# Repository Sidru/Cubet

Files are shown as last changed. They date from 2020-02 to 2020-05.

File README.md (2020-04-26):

# Cubet (CUBID-19) 

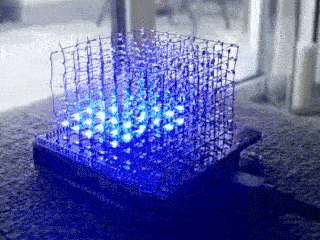
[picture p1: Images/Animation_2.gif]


Cubet, a small single color led cube, build during the Covid-19 Quarantine

:warning: The README is still in working process

:warning: The Software works, but it must be improved. Trying to get the DMA to work with the Timer Counter to automatic set the LATCH output. The animations must be still coded (I've copied some animations and functions from [fuchsales/LED-Cube](https://github.com/fuchsalex/LED-Cube)

I always wanted a LED Cube, a compact one with smd leds. I also wanted to give KiCad a try (I've been Eagle user for a couple of years). That's why I started this mini project.

My goal was: 
- Small LED Cube, not bigger than 5cm
- No extra power needed (USB powered)
- Cheap (i.e. Shift Register instead of "expensive" LED Drivers, no SK6812/ws2811 leds)
- Designed with KiCad

I started with the Schematic and Layout in January, and the PCB came together with COVID, so I had plenty of time to solder.
I gave my cube the name of Cubet (catalan word for small cube), but CUBID is also a good name :)

The microcontroller is a SAMD21, with native USB, so no FTDI or similar is needed. It' a simple Arduino Zero compatible board, like the Feather M0 from Adafruit
It uses 74HC595 Shift Registers and a couple of transistors.

My tools are not the best one, and I realized I may need to buy better and new tools. For example my soldering iron is a cheap one and the soldering was quite a challenge (The head was too big for some components, and it didn't get hot enough). 
I also may need a Microscope, it's more pleasant than a magnifying glass. The tweezers were of course also too big. 

For the LED Matrix/Cube I need to develope a helping tool or something similar. My idea was to use 8 big holes in the PCB to put there 8 LEDS and solder them together to get a column. This didn't work as expected so I neede to solder without help.
I used 0.3mm Wire for the columns, and 0.2mm Wire for the rest.

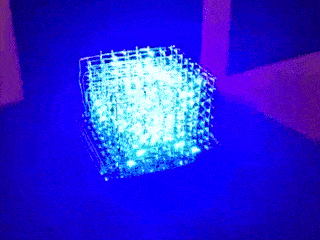
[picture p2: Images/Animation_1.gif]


## Getting Started

* Install KiCad and make changes to the schematic/layout (if needed)
* Get the PCB from your favourite Producer
* Solder all the components
* Flash the Bootloader (if needed)
* Flash the Software

#### Prerequisites

* A lot of time 
* Patience
* More patience
* Soldering skill
* JTAG Programmer (I used an J\-LINK EDU Mini)
* More time
* Did I mention patience?

### Installing 
#### Flashing the Bootloader
#### Flashing the Software

## Built With

* [KiCad](http://www.kicad-pcb.org)
* [PlatformIO](http://platformio.org)

## Authors

## License

This project is licensed under the Apache License - see the [LICENSE.md](LICENSE.md) file for tedtails

## Acknowledgments

[LED-Cube](https://github.com/fuchsalex/LED-Cube)
[Mini KiCad Tutorial](https://github.com/MalphasWats/hawk)
[KiCad Freerouting](https://github.com/miho/freerouting)
[Gerber Export](https://jnduli.co.ke/prepare-kicad-pcb-elecrow.html)
[PCB from Elecrow](https://www.elecrow.com/pcb-manufacturing.html)
[SAMD21](http://ww1.microchip.com/downloads/en/DeviceDoc/SAM_D21_DA1_Family_DataSheet_DS40001882F.pdf)
[SAMD21 GDB](https://learn.adafruit.com/debugging-the-samd21-with-gdb/setup)
[SAMD21 Bootloader Protection](https://roamingthings.de/posts/use-j-link-to-change-the-boot-loader-protection-of-a-sam-d21)
[Programming a SAMD bootloader using JLink & Linux](https://hackaday.io/page/5997-programming-a-samd-bootloader-using-jlink-linux)
[SAMD21\_DMA](https://aykevl.nl/2019/09/samd21-dma)
[Adafruit\_ZeroDMA](https://github.com/adafruit/Adafruit\_ZeroDMA)

## Future changes

* RGB leds 
* ESP32 for Blueetoth and WLAN
* SPI, I2C and UART connectors for hardware "upgrades"
* Battery connector and battery charging
* Maybe a 12x12x12 and a 16x16x16 version
* SD card for animations without programming

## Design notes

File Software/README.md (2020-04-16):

https://github.com/fuchsalex/LED-Cube/blob/master/Sourcecode/LED_CUBE_source.ino

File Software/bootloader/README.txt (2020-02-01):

https://learn.adafruit.com/debugging-the-samd21-with-gdb/overview
https://hackaday.io/page/5997-programming-a-samd-bootloader-using-jlink-linux
https://roamingthings.de/posts/use-j-link-to-change-the-boot-loader-protection-of-a-sam-d21/

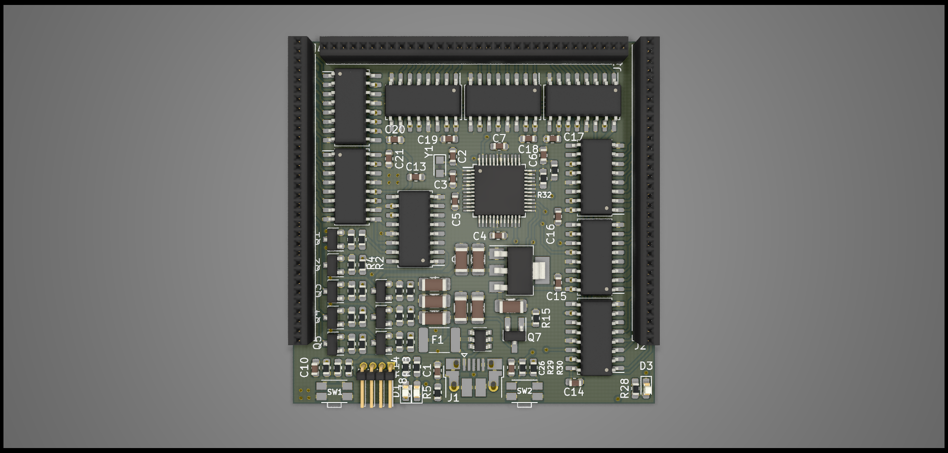
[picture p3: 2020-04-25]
Images/Cubet_PCB.png

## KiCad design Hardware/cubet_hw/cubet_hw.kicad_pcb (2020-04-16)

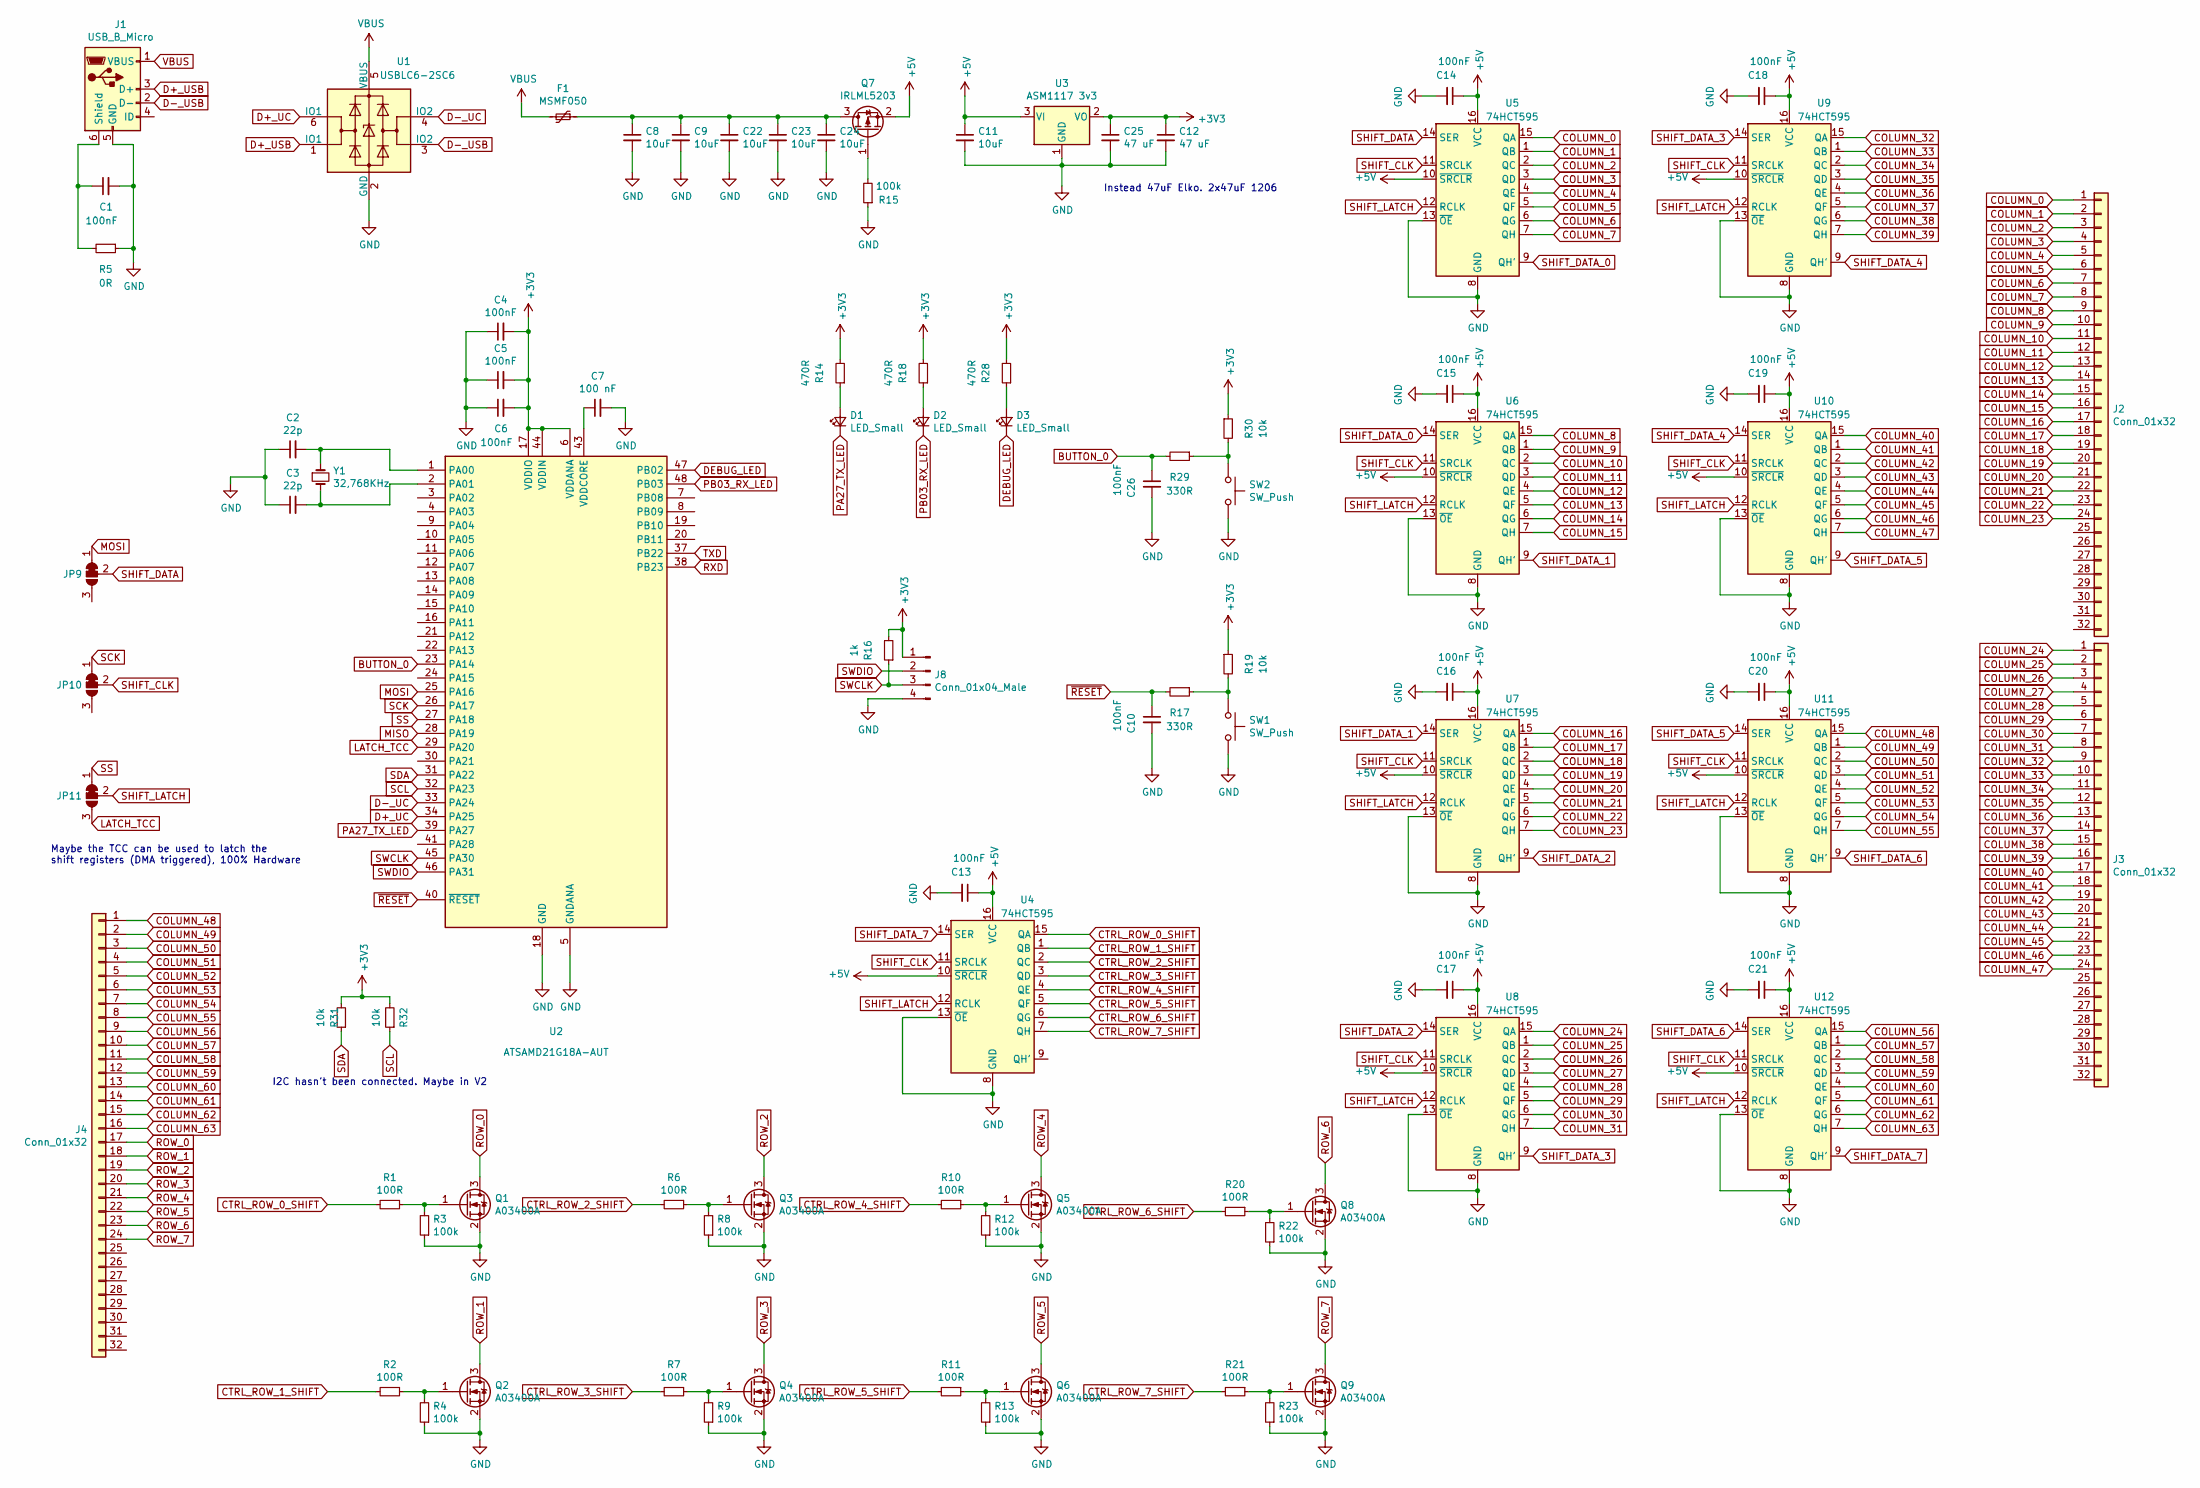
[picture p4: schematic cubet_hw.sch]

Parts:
C1, C4, C5, C6, C10, C13, C14, C15, C16, C17, C18, C19, C20, C21, C26: 100nF; C_0603_1608Metric
C2, C3: 22p; C_0603_1608Metric
C7: 100 nF; C_0603_1608Metric
C8, C9, C11, C22, C23, C24: 10uF; C_1206_3216Metric_Pad1.42x1.75mm_HandSolder
C12, C25: 47 uF; C_1206_3216Metric_Pad1.42x1.75mm_HandSolder
D1, D2, D3: LED_Small; LED_0603_1608Metric_Pad1.05x0.95mm_HandSolder
F1: MSMF050; Fuse_1812_4532Metric_Pad1.30x3.40mm_HandSolder
J1: USB_B_Micro; USB_Micro-B_Amphenol_10103594-0001LF_Horizontal
J2, J3, J4: Conn_01x32; PinSocket_1x32_P1.27mm_Vertical
J8: Conn_01x04_Male; PinHeader_1x04_P1.27mm_Horizontal
JP9, JP10, JP11: SolderJumper_3_Bridged12; SolderJumper-3_P1.3mm_Bridged12_RoundedPad1.0x1.5mm
Q1, Q2, Q3, Q4, Q5, Q6, Q8, Q9: A03400A; SOT-23
Q7: IRLML5203; SOT-23_Handsoldering
R1, R2, R6, R7, R10, R11, R20, R21: 100R; R_0603_1608Metric_Pad1.05x0.95mm_HandSolder
R3, R4, R8, R9, R12, R13, R22, R23: 100k; R_0603_1608Metric_Pad1.05x0.95mm_HandSolder
R5: 0R; R_0603_1608Metric
R14, R18, R28: 470R; R_0603_1608Metric_Pad1.05x0.95mm_HandSolder
R15: 100k; R_0603_1608Metric
R16: 1k; R_0603_1608Metric
R17, R29: 330R; R_0603_1608Metric
R19, R30: 10k; R_0603_1608Metric
R31, R32: 10k; R_0603_1608Metric_Pad1.05x0.95mm_HandSolder
SW1, SW2: SW_Push; SW_SPST_EVQP7A
U1: USBLC6-2SC6; SOT-23-6
U2: ATSAMD21G18A-AUT; TQFP-48_7x7mm_P0.5mm
U3: ASM1117 3v3; SOT-223
U4, U5, U6, U7, U8, U9, U10, U11, U12: 74HCT595; SOP-16_4.55x10.3mm_P1.27mm
Y1: 32,768KHz; Crystal_SMD_2012-2Pin_2.0x1.2mm_HandSoldering

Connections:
+3V3: C4.2, C5.2, C6.2, C12.1, C25.1, J8.1, R14.2, R16.2, R18.2, R19.1, R28.2, R30.1, R31.2, R32.2, U2.6 (VDDANA), U2.17 (VDDIO), U2.36 (VDDIO), U2.44 (VDDIN), U3.2 (VO)
+5V: C11.1, C13.1, C14.1, C15.1, C16.1, C17.1, C18.1, C19.1, C20.1, C21.1, Q7.2 (S), U3.3 (VI), U4.10 (~SRCLR), U4.16 (VCC), U5.10 (~SRCLR), U5.16 (VCC), U6.10 (~SRCLR), U6.16 (VCC), U7.10 (~SRCLR), U7.16 (VCC), U8.10 (~SRCLR), U8.16 (VCC), U9.10 (~SRCLR), U9.16 (VCC), U10.10 (~SRCLR), U10.16 (VCC), U11.10 (~SRCLR), U11.16 (VCC), U12.10 (~SRCLR), U12.16 (VCC)
BUTTON_0: C26.1, R29.2, U2.23 (PA14)
COLUMN_0: J2.1, U5.15 (QA)
COLUMN_1: J2.2, U5.1 (QB)
COLUMN_2: J2.3, U5.2 (QC)
COLUMN_3: J2.4, U5.3 (QD)
COLUMN_4: J2.5, U5.4 (QE)
COLUMN_5: J2.6, U5.5 (QF)
COLUMN_6: J2.7, U5.6 (QG)
COLUMN_7: J2.8, U5.7 (QH)
COLUMN_8: J2.9, U6.15 (QA)
COLUMN_9: J2.10, U6.1 (QB)
COLUMN_10: J2.11, U6.2 (QC)
COLUMN_11: J2.12, U6.3 (QD)
COLUMN_12: J2.13, U6.4 (QE)
COLUMN_13: J2.14, U6.5 (QF)
COLUMN_14: J2.15, U6.6 (QG)
COLUMN_15: J2.16, U6.7 (QH)
COLUMN_16: J2.17, U7.15 (QA)
COLUMN_17: J2.18, U7.1 (QB)
COLUMN_18: J2.19, U7.2 (QC)
COLUMN_19: J2.20, U7.3 (QD)
COLUMN_20: J2.21, U7.4 (QE)
COLUMN_21: J2.22, U7.5 (QF)
COLUMN_22: J2.23, U7.6 (QG)
COLUMN_23: J2.24, U7.7 (QH)
COLUMN_24: J3.1, U8.15 (QA)
COLUMN_25: J3.2, U8.1 (QB)
COLUMN_26: J3.3, U8.2 (QC)
COLUMN_27: J3.4, U8.3 (QD)
COLUMN_28: J3.5, U8.4 (QE)
COLUMN_29: J3.6, U8.5 (QF)
COLUMN_30: J3.7, U8.6 (QG)
COLUMN_31: J3.8, U8.7 (QH)
COLUMN_32: J3.9, U9.15 (QA)
COLUMN_33: J3.10, U9.1 (QB)
COLUMN_34: J3.11, U9.2 (QC)
COLUMN_35: J3.12, U9.3 (QD)
COLUMN_36: J3.13, U9.4 (QE)
COLUMN_37: J3.14, U9.5 (QF)
COLUMN_38: J3.15, U9.6 (QG)
COLUMN_39: J3.16, U9.7 (QH)
COLUMN_40: J3.17, U10.15 (QA)
COLUMN_41: J3.18, U10.1 (QB)
COLUMN_42: J3.19, U10.2 (QC)
COLUMN_43: J3.20, U10.3 (QD)
COLUMN_44: J3.21, U10.4 (QE)
COLUMN_45: J3.22, U10.5 (QF)
COLUMN_46: J3.23, U10.6 (QG)
COLUMN_47: J3.24, U10.7 (QH)
COLUMN_48: J4.1, U11.15 (QA)
COLUMN_49: J4.2, U11.1 (QB)
COLUMN_50: J4.3, U11.2 (QC)
COLUMN_51: J4.4, U11.3 (QD)
COLUMN_52: J4.5, U11.4 (QE)
COLUMN_53: J4.6, U11.5 (QF)
COLUMN_54: J4.7, U11.6 (QG)
COLUMN_55: J4.8, U11.7 (QH)
COLUMN_56: J4.9, U12.15 (QA)
COLUMN_57: J4.10, U12.1 (QB)
COLUMN_58: J4.11, U12.2 (QC)
COLUMN_59: J4.12, U12.3 (QD)
COLUMN_60: J4.13, U12.4 (QE)
COLUMN_61: J4.14, U12.5 (QF)
COLUMN_62: J4.15, U12.6 (QG)
COLUMN_63: J4.16, U12.7 (QH)
CTRL_ROW_0_SHIFT: R1.2, U4.15 (QA)
CTRL_ROW_0_UC: U2.9 (PA04)
CTRL_ROW_1_SHIFT: R2.2, U4.1 (QB)
CTRL_ROW_1_UC: U2.10 (PA05)
CTRL_ROW_2_SHIFT: R6.2, U4.2 (QC)
CTRL_ROW_2_UC: U2.11 (PA06)
CTRL_ROW_3_SHIFT: R7.2, U4.3 (QD)
CTRL_ROW_3_UC: U2.12 (PA07)
CTRL_ROW_4_SHIFT: R10.2, U4.4 (QE)
CTRL_ROW_4_UC: U2.13 (PA08)
CTRL_ROW_5_SHIFT: R11.2, U4.5 (QF)
CTRL_ROW_5_UC: U2.14 (PA09)
CTRL_ROW_6_SHIFT: R20.2, U4.6 (QG)
CTRL_ROW_6_UC: U2.15 (PA10)
CTRL_ROW_7_SHIFT: R21.2, U4.7 (QH)
CTRL_ROW_7_UC: U2.16 (PA11)
D+_UC: U1.6 (IO1), U2.34 (PA25)
D+_USB: J1.3 (D+), U1.1 (IO1)
D-_UC: U1.4 (IO2), U2.33 (PA24)
D-_USB: J1.2 (D-), U1.3 (IO2)
DEBUG_LED: D3.1 (K), U2.47 (PB02)
GND: C1.2, C2.1, C3.1, C4.1, C5.1, C6.1, C7.2, C8.2, C9.2, C10.2, C11.2, C12.2, C13.2, C14.2, C15.2, C16.2, C17.2, C18.2, C19.2, C20.2, C21.2, C22.2, C23.2, C24.2, C25.2, C26.2, J1.5 (GND), J8.4, Q1.2 (S), Q2.2 (S), Q3.2 (S), Q4.2 (S), Q5.2 (S), Q6.2 (S), Q8.2 (S), Q9.2 (S), R3.1, R4.1, R5.1, R8.1, R9.1, R12.1, R13.1, R15.1, R22.1, R23.1, SW1.2, SW2.2, U1.2 (GND), U2.5 (GNDANA), U2.18 (GND), U2.35 (GND), U2.42 (GND), U3.1 (GND), U4.8 (GND), U4.13 (~OE), U5.8 (GND), U5.13 (~OE), U6.8 (GND), U6.13 (~OE), U7.8 (GND), U7.13 (~OE), U8.8 (GND), U8.13 (~OE), U9.8 (GND), U9.13 (~OE), U10.8 (GND), U10.13 (~OE), U11.8 (GND), U11.13 (~OE), U12.8 (GND), U12.13 (~OE)
LATCH_TCC: JP11.3 (B), U2.29 (PA20)
MISO: U2.28 (PA19)
MOSI: JP9.1 (A), U2.25 (PA16)
unnamed: C1.1, J1.6 (Shield), R5.2
unnamed: C2.2, U2.1 (PA00), Y1.1
unnamed: C3.2, U2.2 (PA01), Y1.2
unnamed: C7.1, U2.43 (VDDCORE)
unnamed: C8.1, C9.1, C22.1, C23.1, C24.1, F1.1, Q7.3 (D)
unnamed: D1.2 (A), R14.1
unnamed: D2.2 (A), R18.1
unnamed: D3.2 (A), R28.1
unnamed: Q1.1 (G), R1.1, R3.2
unnamed: Q2.1 (G), R2.1, R4.2
unnamed: Q3.1 (G), R6.1, R8.2
unnamed: Q4.1 (G), R7.1, R9.2
unnamed: Q5.1 (G), R10.1, R12.2
unnamed: Q6.1 (G), R11.1, R13.2
unnamed: Q7.1 (G), R15.2
unnamed: Q8.1 (G), R20.1, R22.2
unnamed: Q9.1 (G), R21.1, R23.2
unnamed: R17.1, R19.2, SW1.1
unnamed: R29.1, R30.2, SW2.1
PA27_TX_LED: D1.1 (K), U2.39 (PA27)
PB03_RX_LED: D2.1 (K), U2.48 (PB03)
PB10_S4_SPI_MOSI: U2.19 (PB10)
PB11_S4_SPI_SCK: U2.20 (PB11)
PB12_S4_SPI_MISO: U2.21 (PA12)
ROW_0: J4.17, Q1.3 (D)
ROW_1: J4.18, Q2.3 (D)
ROW_2: J4.19, Q3.3 (D)
ROW_3: J4.20, Q4.3 (D)
ROW_4: J4.21, Q5.3 (D)
ROW_5: J4.22, Q6.3 (D)
ROW_6: J4.23, Q8.3 (D)
ROW_7: J4.24, Q9.3 (D)
RXD: U2.38 (PB23)
SCK: JP10.1 (A), U2.26 (PA17)
SCL: R32.1, U2.32 (PA23)
SDA: R31.1, U2.31 (PA22)
SHIFT_CLK: JP10.2 (C), U4.11 (SRCLK), U5.11 (SRCLK), U6.11 (SRCLK), U7.11 (SRCLK), U8.11 (SRCLK), U9.11 (SRCLK), U10.11 (SRCLK), U11.11 (SRCLK), U12.11 (SRCLK)
SHIFT_DATA: JP9.2 (C), U5.14 (SER)
SHIFT_DATA_0: U5.9 (QH'), U6.14 (SER)
SHIFT_DATA_1: U6.9 (QH'), U7.14 (SER)
SHIFT_DATA_2: U7.9 (QH'), U8.14 (SER)
SHIFT_DATA_3: U8.9 (QH'), U9.14 (SER)
SHIFT_DATA_4: U9.9 (QH'), U10.14 (SER)
SHIFT_DATA_5: U10.9 (QH'), U11.14 (SER)
SHIFT_DATA_6: U11.9 (QH'), U12.14 (SER)
SHIFT_DATA_7: U4.14 (SER), U12.9 (QH')
SHIFT_LATCH: JP11.2 (C), U4.12 (RCLK), U5.12 (RCLK), U6.12 (RCLK), U7.12 (RCLK), U8.12 (RCLK), U9.12 (RCLK), U10.12 (RCLK), U11.12 (RCLK), U12.12 (RCLK)
SS: JP11.1 (A), U2.27 (PA18)
SWCLK: J8.3, R16.1, U2.45 (PA30)
SWDIO: J8.2, U2.46 (PA31)
TXD: U2.37 (PB22)
VBUS: F1.2, J1.1 (VBUS), U1.5 (VBUS)
~RESET~: C10.1, R17.2, U2.40 (~RESET)

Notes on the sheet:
Instead 47uF Elko. 2x47uF 1206
Maybe the TCC can be used to latch the shift registers (DMA triggered), 100% Hardware
I2C hasn't been connected. Maybe in V2

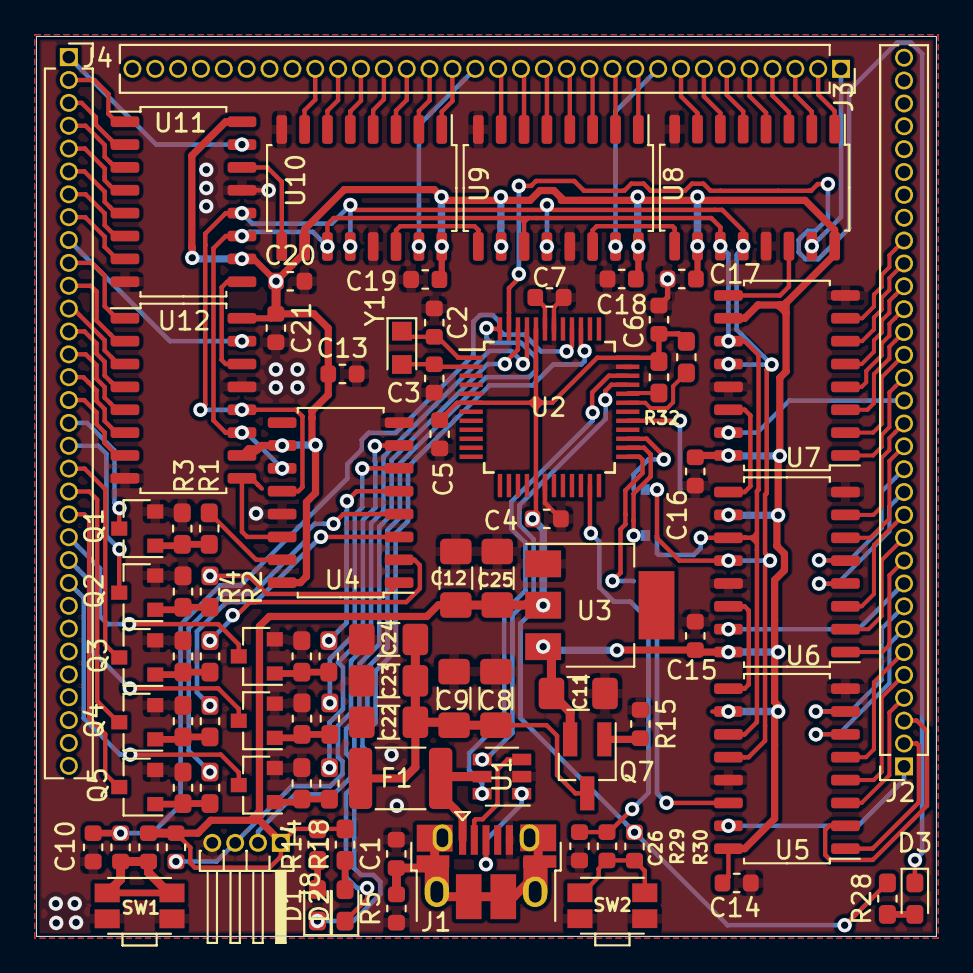
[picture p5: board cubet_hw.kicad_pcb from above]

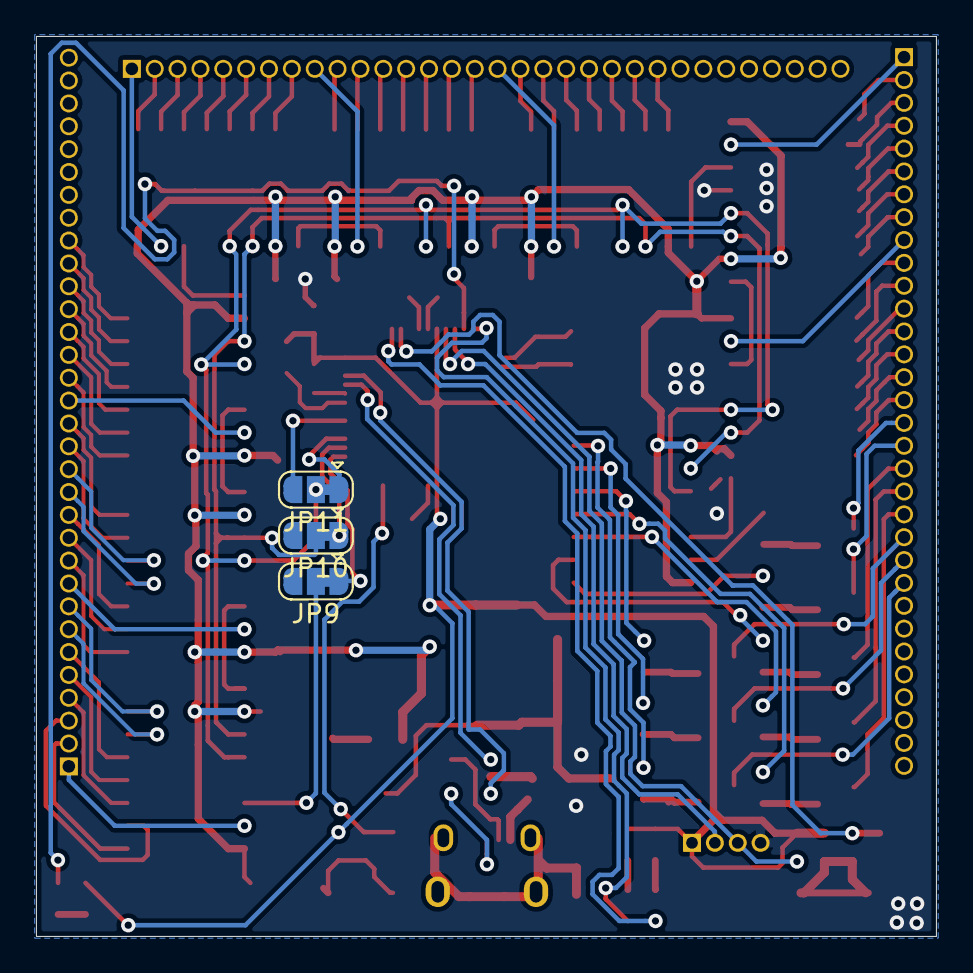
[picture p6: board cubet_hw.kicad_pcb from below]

Board: 2 copper layers, 50.0 x 50.0 mm, 90 parts (3 on the bottom side), 131 nets.

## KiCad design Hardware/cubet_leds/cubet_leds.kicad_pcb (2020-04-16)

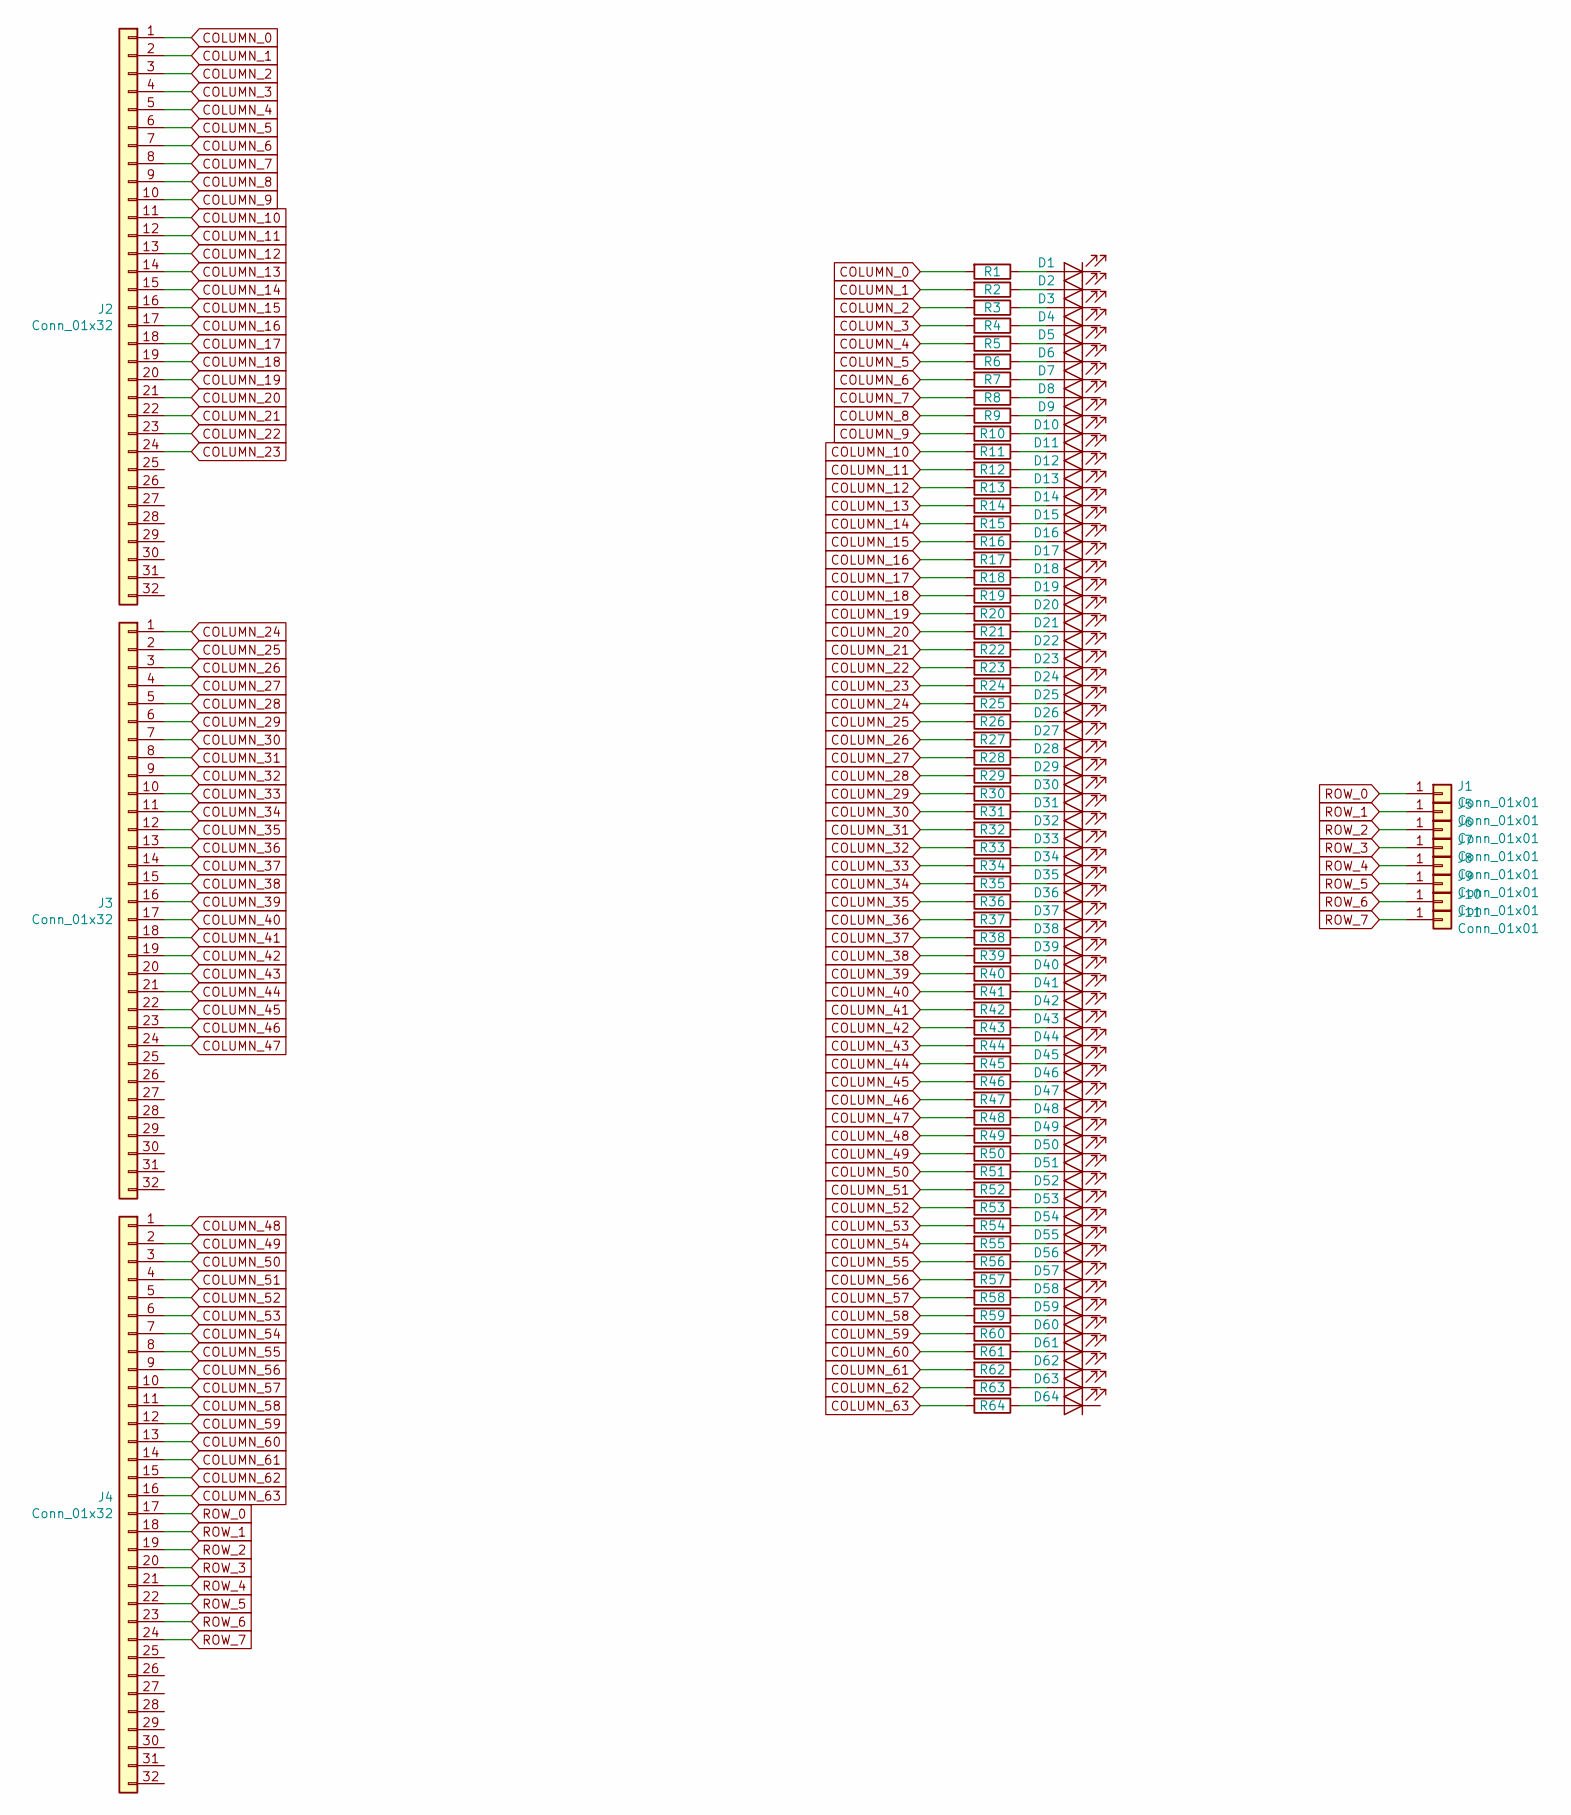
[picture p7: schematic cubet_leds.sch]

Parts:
D1, D2, D3, D4, D5, D6, D7, D8, D9, D10, D11, D12, D13, D14, D15, D16, D17, D18, D19, D20, D21, D22, D23, D24, D25, D26, D27, D28, D29, D30, D31, D32, D33, D34, D35, D36, D37, D38, D39, D40, D41, D42, D43, D44, D45, D46, D47, D48, D49, D50, D51, D52, D53, D54, D55, D56, D57, D58, D59, D60, D61, D62, D63, D64: LED; LED_0603_03Drill
J1, J5, J6, J7, J8, J9, J10, J11: Conn_01x01; TestPoint_THTPad_D1.0mm_Drill0.3mm
J2, J3, J4: Conn_01x32; PinSocket_1x32_P1.27mm_Vertical
R1, R2, R3, R4, R5, R6, R7, R8, R9, R10, R11, R12, R13, R14, R15, R16, R17, R18, R19, R20, R21, R22, R23, R24, R25, R26, R27, R28, R29, R30, R31, R32, R33, R34, R35, R36, R37, R38, R39, R40, R41, R42, R43, R44, R45, R46, R47, R48, R49, R50, R51, R52, R53, R54, R55, R56, R57, R58, R59, R60, R61, R62, R63, R64: R; R_0603_1608Metric

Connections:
COLUMN_0: J2.1, R1.2
COLUMN_1: J2.2, R2.2
COLUMN_2: J2.3, R3.2
COLUMN_3: J2.4, R4.2
COLUMN_4: J2.5, R5.2
COLUMN_5: J2.6, R6.2
COLUMN_6: J2.7, R7.2
COLUMN_7: J2.8, R8.2
COLUMN_8: J2.9, R9.2
COLUMN_9: J2.10, R10.2
COLUMN_10: J2.11, R11.2
COLUMN_11: J2.12, R12.2
COLUMN_12: J2.13, R13.2
COLUMN_13: J2.14, R14.2
COLUMN_14: J2.15, R15.2
COLUMN_15: J2.16, R16.2
COLUMN_16: J2.17, R17.2
COLUMN_17: J2.18, R18.2
COLUMN_18: J2.19, R19.2
COLUMN_19: J2.20, R20.2
COLUMN_20: J2.21, R21.2
COLUMN_21: J2.22, R22.2
COLUMN_22: J2.23, R23.2
COLUMN_23: J2.24, R24.2
COLUMN_24: J3.1, R25.2
COLUMN_25: J3.2, R26.2
COLUMN_26: J3.3, R27.2
COLUMN_27: J3.4, R28.2
COLUMN_28: J3.5, R29.2
COLUMN_29: J3.6, R30.2
COLUMN_30: J3.7, R31.2
COLUMN_31: J3.8, R32.2
COLUMN_32: J3.9, R33.2
COLUMN_33: J3.10, R34.2
COLUMN_34: J3.11, R35.2
COLUMN_35: J3.12, R36.2
COLUMN_36: J3.13, R37.2
COLUMN_37: J3.14, R38.2
COLUMN_38: J3.15, R39.2
COLUMN_39: J3.16, R40.2
COLUMN_40: J3.17, R41.2
COLUMN_41: J3.18, R42.2
COLUMN_42: J3.19, R43.2
COLUMN_43: J3.20, R44.2
COLUMN_44: J3.21, R45.2
COLUMN_45: J3.22, R46.2
COLUMN_46: J3.23, R47.2
COLUMN_47: J3.24, R48.2
COLUMN_48: J4.1, R49.2
COLUMN_49: J4.2, R50.2
COLUMN_50: J4.3, R51.2
COLUMN_51: J4.4, R52.2
COLUMN_52: J4.5, R53.2
COLUMN_53: J4.6, R54.2
COLUMN_54: J4.7, R55.2
COLUMN_55: J4.8, R56.2
COLUMN_56: J4.9, R57.2
COLUMN_57: J4.10, R58.2
COLUMN_58: J4.11, R59.2
COLUMN_59: J4.12, R60.2
COLUMN_60: J4.13, R61.2
COLUMN_61: J4.14, R62.2
COLUMN_62: J4.15, R63.2
COLUMN_63: J4.16, R64.2
unnamed: D1.2 (A), R1.1
unnamed: D2.2 (A), R2.1
unnamed: D3.2 (A), R3.1
unnamed: D4.2 (A), R4.1
unnamed: D5.2 (A), R5.1
unnamed: D6.2 (A), R6.1
unnamed: D7.2 (A), R7.1
unnamed: D8.2 (A), R8.1
unnamed: D9.2 (A), R9.1
unnamed: D10.2 (A), R10.1
unnamed: D11.2 (A), R11.1
unnamed: D12.2 (A), R12.1
unnamed: D13.2 (A), R13.1
unnamed: D14.2 (A), R14.1
unnamed: D15.2 (A), R15.1
unnamed: D16.2 (A), R16.1
unnamed: D17.2 (A), R17.1
unnamed: D18.2 (A), R18.1
unnamed: D19.2 (A), R19.1
unnamed: D20.2 (A), R20.1
unnamed: D21.2 (A), R21.1
unnamed: D22.2 (A), R22.1
unnamed: D23.2 (A), R23.1
unnamed: D24.2 (A), R24.1
unnamed: D25.2 (A), R25.1
unnamed: D26.2 (A), R26.1
unnamed: D27.2 (A), R27.1
unnamed: D28.2 (A), R28.1
unnamed: D29.2 (A), R29.1
unnamed: D30.2 (A), R30.1
unnamed: D31.2 (A), R31.1
unnamed: D32.2 (A), R32.1
unnamed: D33.2 (A), R33.1
unnamed: D34.2 (A), R34.1
unnamed: D35.2 (A), R35.1
unnamed: D36.2 (A), R36.1
unnamed: D37.2 (A), R37.1
unnamed: D38.2 (A), R38.1
unnamed: D39.2 (A), R39.1
unnamed: D40.2 (A), R40.1
unnamed: D41.2 (A), R41.1
unnamed: D42.2 (A), R42.1
unnamed: D43.2 (A), R43.1
unnamed: D44.2 (A), R44.1
unnamed: D45.2 (A), R45.1
unnamed: D46.2 (A), R46.1
unnamed: D47.2 (A), R47.1
unnamed: D48.2 (A), R48.1
unnamed: D49.2 (A), R49.1
unnamed: D50.2 (A), R50.1
unnamed: D51.2 (A), R51.1
unnamed: D52.2 (A), R52.1
unnamed: D53.2 (A), R53.1
unnamed: D54.2 (A), R54.1
unnamed: D55.2 (A), R55.1
unnamed: D56.2 (A), R56.1
unnamed: D57.2 (A), R57.1
unnamed: D58.2 (A), R58.1
unnamed: D59.2 (A), R59.1
unnamed: D60.2 (A), R60.1
unnamed: D61.2 (A), R61.1
unnamed: D62.2 (A), R62.1
unnamed: D63.2 (A), R63.1
unnamed: D64.2 (A), R64.1
ROW_0: J1.1, J4.17
ROW_1: J4.18, J5.1
ROW_2: J4.19, J6.1
ROW_3: J4.20, J7.1
ROW_4: J4.21, J8.1
ROW_5: J4.22, J9.1
ROW_6: J4.23, J10.1
ROW_7: J4.24, J11.1

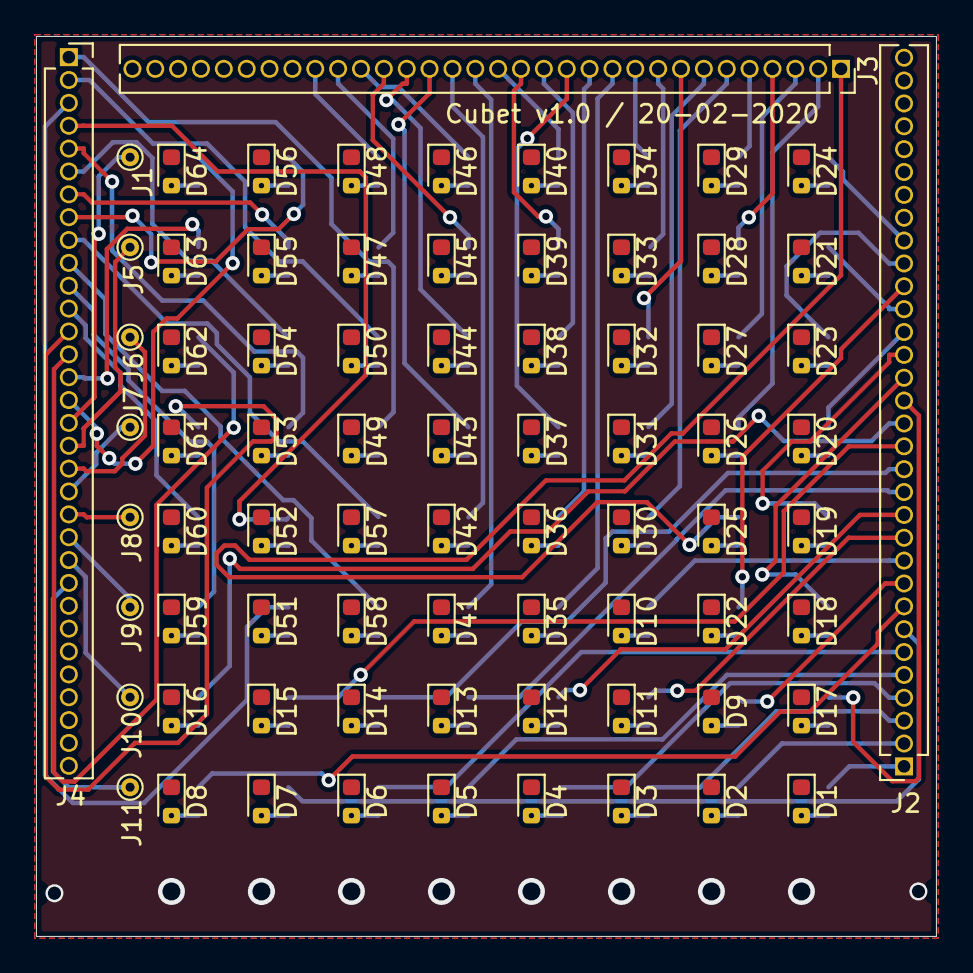
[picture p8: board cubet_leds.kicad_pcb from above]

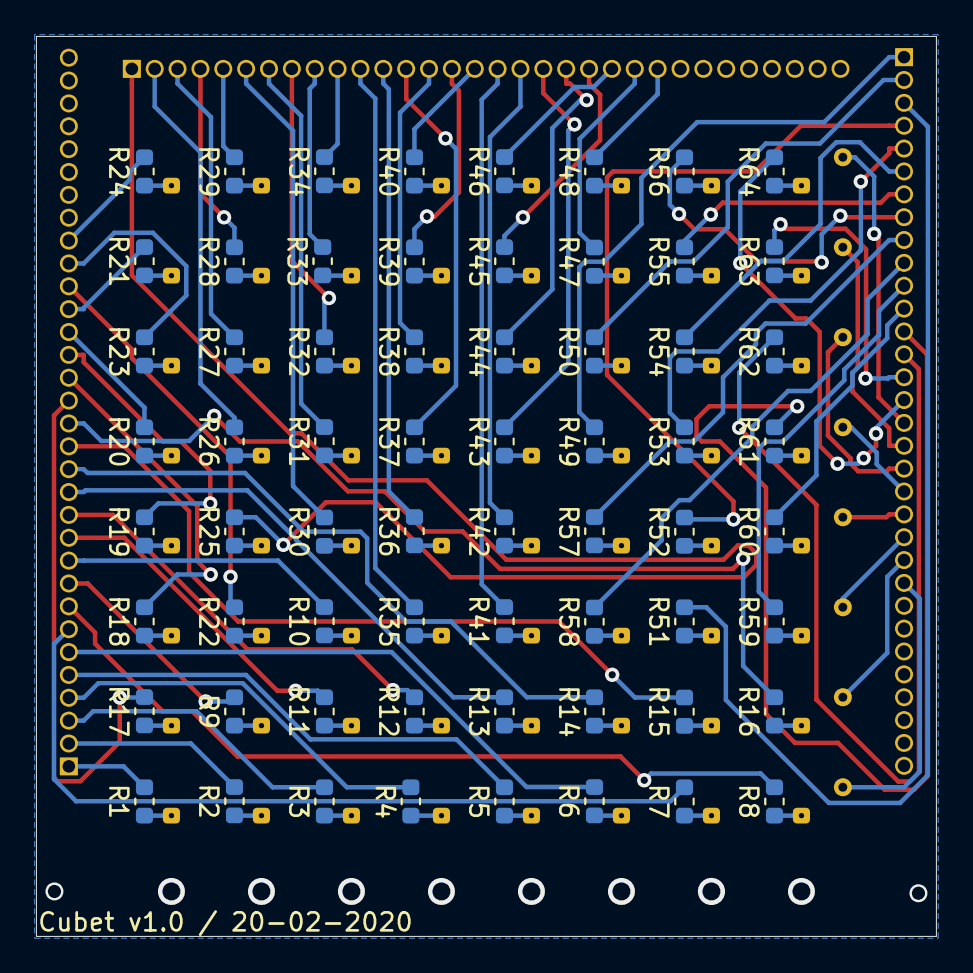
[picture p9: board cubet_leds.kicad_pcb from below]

Board: 2 copper layers, 50.0 x 50.0 mm, 139 parts (64 on the bottom side), 136 nets.

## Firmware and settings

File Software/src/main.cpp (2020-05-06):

#include <Arduino.h>
#include <ArduinoLog.h>

#include <configuration.h>
#include <cube.h>
#include <draw.h>
#include <animations.h>

/* These functions were used to test the Board */
static inline void toggle_led_debug(void);
static inline void init_led_debug(void);

cCube Cubet;
cAnim Anim;

void setup()
{
    Serial.begin(115200);
    Serial.println("Hello World");
    Log.begin(LOG_LEVEL_VERBOSE, &Serial);

    init_led_debug();
    Cubet.begin();
    Anim.begin(&Cubet);
}


void loop()
{
    toggle_led_debug();
    Anim.refresh();
    Cubet.refresh();
}    


void init_led_debug(void)
{
    // initialize LED digital pin as an output.
    pinMode(DEBUG_LED_PIN, OUTPUT);
    pinMode(BUTTON_PIN, INPUT);
}

void toggle_led_debug(void)
{
    static bool last = 0;
    static unsigned long start_millis = millis();
    
    if (digitalRead(BUTTON_PIN) == (bool)0) // Test the Board Button
    {
        if ((millis() - start_millis) >= 250)
        {
            start_millis = millis();
            last = !last;
            digitalWrite(DEBUG_LED_PIN, (bool)last);
        }

    }
    else if ((millis() - start_millis) >= 1000)
    {
        start_millis = millis();
        last = !last;
        digitalWrite(DEBUG_LED_PIN, (bool)last);
    }
}

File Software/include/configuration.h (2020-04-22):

#ifndef CONFIGURATION_H
#define CONFIGURATION_H

/* PINS */
#define DEBUG_LED_PIN   19  // PIN_PB02 -> 19 for Arduino
#define BUTTON_PIN      2   // PIN_PA14 -> 2 for Arduino
#define SHIFT_DATA_PIN  11  // PIN_PA16 -> 11 for Arduino
#define SHIFT_CLK_PIN   13  // PIN_PA17 -> 13 for Arduino
#define SHIFT_LATCH_PIN 10  // PIN_PA18 -> 10 for Arduino
#define SHIFT_READ_PIN  9   // PIN_PA07 -> 9 for Arduino. Not used, only to test the Shifty library


/* CUBE */
#define SIZE_OF_X 8     // Number of leds in x 
#define SIZE_OF_Y 8     // Number of leds in y
#define SIZE_OF_Z 8     // Number of leds in z

#define SINGLE_COLOR_CUBE       // Uncomment this in case you are using a single LED Cube
//#define MULTIPLE_COLOR_CUBE   // Uncomennt this in case you are using an RGB LED Cube


#define FRAMES_PER_SECOND   25
#define PWM_RESOLUTION      32 
//#define PWM


#define CUBE_REFRESH_MS 1


/* SHIFT REGISTER */
//#define SHIFT_SOFTWARE
//#define SHIFT_SPI
#define SHIFT_SPI_DMA
//#define SHIFT_SPI_DMA_TC




#define ARRAY_LAYER_SIZE (((uint32_t)SIZE_OF_X * (uint32_t)SIZE_OF_Y)/8 + ((uint32_t)SIZE_OF_Z/8))

#endif

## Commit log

2019-10-06 Schaltplan fast fertig
    [PartList.ods, cubet_hw.kicad_pcb, cubet_hw.sch]
2020-02-01 bootloader flashed, ready to program
    [arduino_zero.cfg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]
2020-02-01 Unnötige Dateien löschen
    [arduino_zero.cfg]
2020-02-01 First hardware tests...
    [configuration.h]
2020-02-21 LEDs PCB bestellt
    [cubet_leds.kicad_pcb, cubet_leds.sch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]
2020-04-16 First working SPI. First work in README
    [PartList.ods, configuration.h, cubet_hw.kicad_pcb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]
2020-04-22 Importing effects from Alex Fuchs Cube
    [configuration.h]
